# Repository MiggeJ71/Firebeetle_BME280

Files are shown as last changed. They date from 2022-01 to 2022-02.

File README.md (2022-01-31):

# Firebeetle_BME280

Battery powered ESP32 based IoT device to measure and report weather data and battery level as MQTT messages. R10 and R11 has been bridged on the Firebeetle board in order to measure battery voltage on pin A0.
Estimated battery life on a single battery is about 940 days if measurement data is sent every 15 minutes and. At that time the battery is estimated to be down at 20% SOC.

Note!
DFRobot driver for BME280 had to be modified (patch uploaded on DFRobot Github page) in order to get correct values for humidity. 

ESP powered by a single Lifepo4 battery
Note! These batteries claim to have a capacity of 7200mA but are in fact 5200mA in average.

Products used
ESP32 https://www.dfrobot.com/product-1590.html

BME280 https://www.aliexpress.com/item/32849462236.html?spm=a2g0o.9042311.0.0.259e4c4d16GiDw

Battery https://www.aliexpress.com/item/1005001997843247.html?spm=a2g0o.9042311.0.0.259e4c4d16GiDw

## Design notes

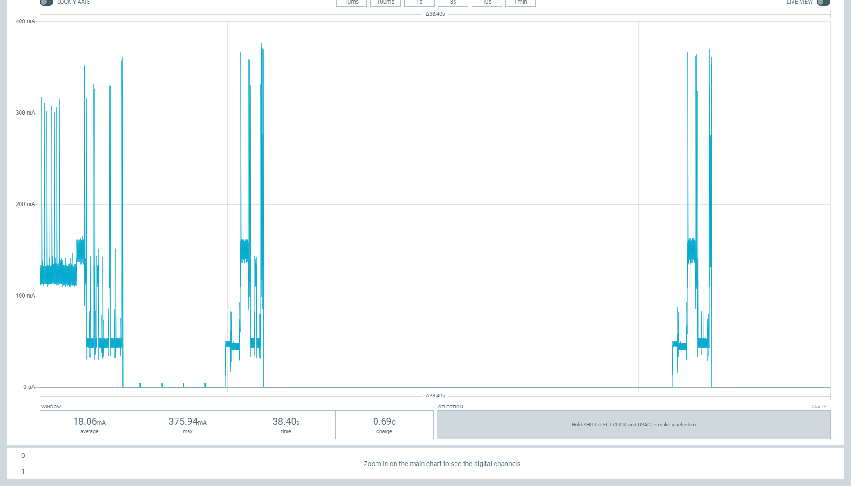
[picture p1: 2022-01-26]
ppk-20220124T182000.png

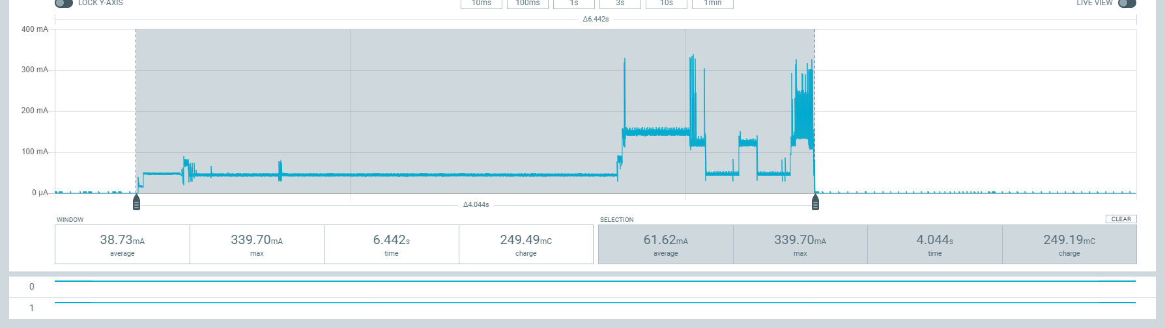
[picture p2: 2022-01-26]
ppk-20220120T194607.png

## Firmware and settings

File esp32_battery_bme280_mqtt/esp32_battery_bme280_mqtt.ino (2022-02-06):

// ToDo:
// - Add secure MQTT using SSL

// Log all to Serial, comment this line to disable logging
//#define LOG Serial
// Include must be placed after LOG definition to work
#include "log.h"

// WiFi access
#include "wifi_access.h"

#include "esp_adc_cal.h"
#include <DFRobot_BME280.h>
#include <Wire.h>
#include <WiFi.h>

extern "C" {
  #include "freertos/FreeRTOS.h"
  #include "freertos/timers.h"
}
#include <MQTT.h>

// ******** use abbreviations instead of full names ********
typedef DFRobot_BME280_IIC    BME;    

/**IIC address is 0x76 when pin SDO is low  (SIM7000)*/
BME   bme(&Wire, 0x76);   // select TwoWire peripheral and set sensor address

#define SEA_LEVEL_PRESSURE    1015.0f

// Define alarm levels
#define NO_ALARM 0
#define ALARM_LOW 1
#define ALARM_MEDIUM 2
#define ALARM_HIGH 3


// Define sleep time
#define INITIAL_SLEEP_TIME 5*1000000ULL  /* initail sleep time at start-up, 5s */
#define SLEEP_TIME 900*1000000ULL   /* sleep time between wake-ups, 900s (15min) */

// Define battery voltage levels
#define LOW_BATTERY_VOLTAGE 3.00
#define VERY_LOW_BATTERY_VOLTAGE 2.90
#define CRITICALLY_LOW_BATTERY_VOLTAGE 2.80

// MQTT Topics
#define MQTT_PUB_TEMP "esp32/bme280/IoT_3/temperature"
#define MQTT_PUB_HUM "esp32/bme280/IoT_3/humidity"
#define MQTT_PUB_PRES "esp32/bme280/IoT_3/pressure"
#define MQTT_PUB_BATT "esp32/bme280/IoT_3/battery"
#define MQTT_PUB_RESTARTS "esp32/bme280/IoT_3/restarts"
#define MQTT_PUB_ALARM "esp32/bme280/IoT_3/alarm"

// include definition of MQTT access to broker
// MQTT_USER
// MQTT_PASSWORD
// MQTT_BROKER
// MQTT_PORT
#include "MQTT_access.h"
String MQTTDeviceName = "Firebeetle";



// Define parameters to store in RTC memory to survive deep sleep
RTC_NOINIT_ATTR struct {
  uint8_t bssid[6];
  uint8_t channel;
  float BatteryVoltage;      //battery voltage in V
  uint64_t NumberOfRestarts; //number of restarts
  uint8_t alarm;             //last alarm
} cache;


// show last sensor operate status
void printLastOperateStatus(BME::eStatus_t eStatus)
{
  switch(eStatus) {
  case BME::eStatusOK:
    log_println("BME280 everything ok");
    break;
  case BME::eStatusErr:
    log_println("BME280 unknow error");
    break;
  case BME::eStatusErrDeviceNotDetected:
    log_println("BME280 device not detected");
    break;
  case BME::eStatusErrParameter:
    log_println("BME280 parameter error");
    break;
  default:
    log_println("BME280 unknow status");
    break;
  }
}

/******************************************************************************
Description.: reads the battery voltage through the voltage divider at GPIO36 (A0)
              if the ESP32-E has calibration eFused those will be used.
              In comparison with a regular voltmeter the values of ESP32 and
              multimeter differ only about 0.05V
Input Value.: -
Return Value: battery voltage in volts
******************************************************************************/
float readBattery() {
  uint32_t value = 0;
  int rounds = 11;
  esp_adc_cal_characteristics_t adc_chars;

  //battery voltage divided by 2 can be measured at GPIO34, which equals ADC1_CHANNEL6
  adc1_config_width(ADC_WIDTH_BIT_12);
  adc1_config_channel_atten(ADC1_CHANNEL_0, ADC_ATTEN_DB_11);
  switch(esp_adc_cal_characterize(ADC_UNIT_1, ADC_ATTEN_DB_11, ADC_WIDTH_BIT_12, 1100, &adc_chars)) {
    case ESP_ADC_CAL_VAL_EFUSE_TP:
      log_println("Characterized using Two Point Value");
      break;
    case ESP_ADC_CAL_VAL_EFUSE_VREF:
      log_printf("Characterized using eFuse Vref (%d mV)\r\n", adc_chars.vref);
      break;
    default:
      log_printf("Characterized using Default Vref (%d mV)\r\n", 1100);
  }

  //to avoid noise, sample the pin several times and average the result
  for(int i=1; i<=rounds; i++) {
    value += adc1_get_raw(ADC1_CHANNEL_0);
    log_printf("ADC value : %d\n", value);
  }
  value /= (uint32_t)rounds;
  
  //due to the voltage divider (1M+1M) values must be multiplied by 2
  //and convert mV to V
  return esp_adc_cal_raw_to_voltage(value, &adc_chars)*2/1000.0;
}


/******************************************************************************
Description.: brings the WiFi up
Input Value.: When "tryCachedValuesFirst" is true the function tries to use
              cached values before attempting a scan + association
Return Value: true if WiFi is up, false if it timed out
******************************************************************************/
bool WiFiUP(bool tryCachedValuesFirst) {
  WiFi.persistent(false);
  WiFi.mode(WIFI_STA);
  
  if(tryCachedValuesFirst && cache.channel > 0) {
    log_printf("Cached values as follows:\r\n");
    log_printf(" Channel....: %d\r\n", cache.channel);
    log_printf(" BSSID......: %x:%x:%x:%x:%x:%x\r\n", cache.bssid[0], \
                                                         cache.bssid[1], \
                                                         cache.bssid[2], \
                                                         cache.bssid[3], \
                                                         cache.bssid[4], \
                                                         cache.bssid[5]);

    WiFi.begin(WIFI_SSID, WIFI_PASSWORD, cache.channel, cache.bssid);

    for (unsigned long i=millis(); millis()-i < 10000;) {
      delay(10);

      if (WiFi.status() == WL_CONNECTED) {
        log_printf("WiFi connected with cached values (%lu)\r\n", millis()-i);
        return true;
      } 
    }
  }

  cache.channel = 0;
  for (uint32_t i = 0; i < sizeof(cache.bssid); i++)
    cache.bssid[i] = 0;

  // try it with the slower process
  WiFi.begin(WIFI_SSID, WIFI_PASSWORD);
  
  for (unsigned long i=millis(); millis()-i < 60000;) {
    delay(10);
  
    if (WiFi.status() == WL_CONNECTED) {
      log_printf("WiFi connected (%lu)\r\n", millis()-i);
  
      uint8_t *bssid = WiFi.BSSID();
      for (uint32_t i = 0; i < sizeof(cache.bssid); i++)
        cache.bssid[i] = bssid[i];
      cache.channel = WiFi.channel();
    
      return true;
    }
  }

  log_printf("WiFi NOT connected\r\n");
  return false;
}


/******************************************************************************
Description.: Reads sensor values and sends all data as MQTT messages
Return Value: true if OK, false if errors occured
******************************************************************************/
bool ReadAndPushSensors() {
  char buf[256] = {0};
   
  log_printf("Reading sensors\n");

  //read RTC
  struct timeval tv;
  gettimeofday(&tv, NULL);
  
  log_printf("Start reading sensor values\n");
   // New BME280 sensor readings

  float   temp = bme.getTemperature();
  uint32_t    press = bme.getPressure()/100;
  //float   alti = bme.calAltitude(SEA_LEVEL_PRESSURE, press);
  float   humi = bme.getHumidity();

  log_printf("Temp = %f\n", temp);
  log_printf("Press = %d\n", press);
  log_printf("Humi = %f\n", humi);

  //establish connection to MQTT server
  WiFiClient net;
  MQTTClient MQTTClient;
  MQTTClient.setTimeout(5000);
  MQTTClient.begin(MQTT_BROKER, MQTT_PORT, net);

  if( MQTTClient.connect(MQTTDeviceName.c_str(), MQTT_USER, MQTT_PASSWORD, false)) { 
    MQTTClient.publish(MQTT_PUB_TEMP, String(temp).c_str(), false, 2);
    MQTTClient.publish(MQTT_PUB_HUM, String(humi).c_str(), false, 2);
    MQTTClient.publish(MQTT_PUB_PRES, String(press).c_str(), false, 2);
    MQTTClient.publish(MQTT_PUB_BATT, String(cache.BatteryVoltage, 3), false, 2);
    snprintf(buf, sizeof(buf)-1, "%llu", cache.NumberOfRestarts);
    MQTTClient.publish(MQTT_PUB_RESTARTS, buf, false, 2);
    MQTTClient.publish(MQTT_PUB_ALARM, String(cache.alarm).c_str(), false, 2);
    
    return true;
  }

  return false;
}


/******************************************************************************
Description.: since this is a battery sensor, everything happens in setup
              and when the tonguing' is done the device enters deep-sleep
Input Value.: -
Return Value: -
******************************************************************************/
void setup() {
  bool status = false;
  bool reportVoltage = false;
  esp_reset_reason_t resetReason = esp_reset_reason();
  int countFail = 0;
  cache.alarm = NO_ALARM;

  //visual feedback when we are active, turn on onboard LED
  pinMode(2, OUTPUT);
  digitalWrite(2, HIGH);

  cache.NumberOfRestarts++;

  Serial.begin(115200);

  log_printf("===================================================\r\n");
  log_printf("FireBeetle active\r\n" \
                " Compiled at: " __DATE__ " - " __TIME__ "\r\n" \
                " ESP-IDF: %s\r\n", esp_get_idf_version());

  log_printf("ESP_RST_POWERON = %d\n", ESP_RST_POWERON);
  log_printf("ESP_RST_DEEPSLEEP = %d\n", ESP_RST_DEEPSLEEP);

  //read battery voltage
  cache.BatteryVoltage = readBattery();  
  // To be used while connected with USB and no battery
  //cache.BatteryVoltage = 3.4;  
  log_printf("Voltage: %4.3f V\r\n", cache.BatteryVoltage);
    
  //a reset is required to wakeup again from below CRITICALLY_LOW_BATTERY_VOLTAGE
  //this is to prevent damaging the empty battery by saving as much power as possible
  //if battery is below VER_LOW_BATTERY_VOLTAGE but still above CRITICALLY_LOW_BATTERY_VOLTAGE, 
  //stop doing the regular work
  //this way the battery can run low, put still wakeup without physical interaction
  if (cache.BatteryVoltage < VERY_LOW_BATTERY_VOLTAGE) {
    if (cache.BatteryVoltage < CRITICALLY_LOW_BATTERY_VOLTAGE) {
      log_println("Battery critically low, hibernating...");
      cache.alarm = ALARM_HIGH;
      //switch off everything that might consume power
      esp_sleep_pd_config(ESP_PD_DOMAIN_RTC_SLOW_MEM, ESP_PD_OPTION_OFF);
      esp_sleep_pd_config(ESP_PD_DOMAIN_RTC_FAST_MEM, ESP_PD_OPTION_OFF);
      esp_sleep_pd_config(ESP_PD_DOMAIN_RTC_PERIPH, ESP_PD_OPTION_OFF);
      esp_sleep_pd_config(ESP_PD_DOMAIN_XTAL, ESP_PD_OPTION_OFF);
      //esp_sleep_pd_config(ESP_PD_DOMAIN_VDDSDIO, ESP_PD_OPTION_OFF);
      //esp_sleep_pd_config(ESP_PD_DOMAIN_CPU, ESP_PD_OPTION_OFF);

      //disable all wakeup sources
      esp_sleep_disable_wakeup_source(ESP_SLEEP_WAKEUP_ALL);
    } else {
      log_println("Battery very low, deep sleeping...");
      cache.alarm = ALARM_MEDIUM;
      //sleep ~60 minutes if battery is between CRITICALLY_LOW_BATTERY_VOLTAGE to VERY_LOW_BATTERY_VOLTAGE
      uint64_t sleeptime = 60*60*1000000ULL;
      esp_sleep_enable_timer_wakeup(sleeptime);
    }

    digitalWrite(2, LOW);
    esp_deep_sleep_start();

    log_println("This should never get printed");
    return;
  }

   if (cache.BatteryVoltage < LOW_BATTERY_VOLTAGE)
     cache.alarm = ALARM_LOW;

  log_printf("Reset value = %d\n", resetReason);
  //check if a reset/power-on occured
  if (resetReason == ESP_RST_POWERON || resetReason == ESP_RST_WDT) {
      cache.NumberOfRestarts = 0;

      //set RTC to 0
      struct timeval tv;
      tv.tv_sec = 0;
      tv.tv_usec = 0;
      settimeofday(&tv, NULL);

    if (resetReason == ESP_RST_POWERON) {
      log_printf("ESP was just switched ON\r\n");
    } else {
      log_printf("ESP was just reset\r\n");
      log_println("bme read data test");
      
      while(bme.begin() != BME::eStatusOK) {
        log_println("bme begin faild");
        countFail++;
        printLastOperateStatus(bme.lastOperateStatus);
        delay(1000);
        if (countFail > 20)
          break;
      }

      bme.setConfigFilter(BME::eConfigFilter_off);        // set config filterto OFF as we do weather measurements
      bme.setConfigTStandby(BME::eConfigTStandby_1000);   // set standby time
      bme.setCtrlMeasSamplingTemp(BME::eSampling_X1);     // set temperature over sampling
      bme.setCtrlMeasSamplingPress(BME::eSampling_X1);    // set pressure over sampling
      bme.setCtrlHumiSampling(BME::eSampling_X1);         // set humidity over sampling
      bme.setCtrlMeasMode(BME::eCtrlMeasMode_forced);     // set control measurement mode to measure once and then return to sleep, needs to be repeated for each measurment
    }

    //default is to have WiFi off
    if (WiFi.getMode() != WIFI_OFF) {
      log_printf("WiFi wasn't off!\r\n");
      WiFi.persistent(true);
      WiFi.mode(WIFI_OFF);
    }

    //try to connect
    WiFiUP(false);
    WiFi.disconnect(true, true);

    esp_sleep_enable_timer_wakeup(INITIAL_SLEEP_TIME);
  }

  // check if ESP returns from deepsleep
  if (resetReason == ESP_RST_DEEPSLEEP) {
    switch(esp_sleep_get_wakeup_cause()) {
      case ESP_SLEEP_WAKEUP_TIMER:
        log_printf("ESP woke up due to timer\r\n");

        while(bme.begin() != BME::eStatusOK) {
          log_println("bme begin faild");
          countFail++;
          printLastOperateStatus(bme.lastOperateStatus);
          delay(1000);
          if (countFail > 20)
            break;
        }

        // set control measurement mode to measure once and then return to sleep, needs to be repeated for each measurment
        bme.setCtrlMeasMode(BME::eCtrlMeasMode_forced);
        
        WiFiUP(true);
        ReadAndPushSensors();
        WiFi.disconnect(true, true);
        
        esp_sleep_enable_timer_wakeup(SLEEP_TIME);
        break;
    
      default:
        log_printf("ESP woke due to an unknown reason\r\n");
    }
  }

  log_printf("=== entering deepsleep after %d ms ===\r\n", millis());
  digitalWrite(2, LOW);
  esp_deep_sleep_start();
  
  log_println("This should never get printed");  
}

void loop() {
  // loop not used as all code is running in setup()
  log_println("This should never get printed");

}

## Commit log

2022-01-31 Update README.md
    Corrected components to be bridged to measure batt voltage
2022-01-31 new file: Firebeetle_BME280_schema.kicad_sch
    [Firebeetle_BME280_schema.kicad_sch]
2022-02-06 Changes to be committed: modified: .gitignore modified: esp32_battery_bme280_mqtt.ino new file: log.h
2022-02-06 Changes to be committed: new file: esp32_battery_bme280_mqtt/MQTT_access.h new file: esp32_battery_bme280_mqtt/esp32_battery_bme280_mqtt.ino new file: esp32_battery_bme280_mqtt/log.h new file: esp32_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
2022-02-06 Delete esp32_battery_bme280_mqtt.ino
    Moved to esp32 directory one level below
